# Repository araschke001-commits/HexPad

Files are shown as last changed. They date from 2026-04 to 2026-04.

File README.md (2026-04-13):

# HexPad
This is a macropad with 6 keys, a rotary encoder, and an oled display. Almost everything in the cad file for this project is customizable. You can add as many keys as you want, change the dimensions of the usb c port, the inside dimensions, the wall dimensions, and basically everything else.

You would use my project by pressing the keys to perform specific functions on the computer, like a simple key press like the number 1, or later I might change it to open a site or type a password in. The rotary encoder is to change volume and mute/unmute it. The oled display is to indicate if a button was pressed/changed.

The reason why I made this project is to learn how to build things like this project so in the future I can make other things similar to this.

## Features:
- 3d printed case
- 6 keys (2 rows of 3)
- 0.91" OLED display
- Rotary encoder
- Almost everything is customizable for the CAD design.

## CAD Model:
It is put together with 4 M3 Screws that go directly into the plastic of the case.

It is made of 2 separate 3d printed parts, the top and the bottom.

Here is the share link to the project: https://cad.onshape.com/documents/888c45d35c64a39055184245/w/6328c76e156d93114c845f2d/e/f25f9ae1fe243c3fda6125d5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

CAD Model:
Screenshot from 2026-04-12 15-23-01

Made in Onshape.

## PCB:
This PCB was made in KiCad.

Schematic:
Screenshot from 2026-04-07 09-58-41

PCB:
Screenshot from 2026-04-11 17-42-04

In hindsight, I maybe should have used a matrix to wire the switches, but it was simpler not to.

## Firmware:
This project uses C++ as firmware because I was unable to get the QMK firmware to work and I already had experience writing code in C++ (I did have to look up how to do some of the arduino stuff though).

The 6 keys act as a partial number pad for now. The oled is to display the last action, and the rotary encoder is to change volume and mute/unmute it.

## BOM:
This should be everything needed for my hackpad:
- Seeed Studio XIAO RP2040	(1x)
- Cherry MX Keycap - R2 (Opaque Black)	(6x)
- Cherry MX Brown 55g Tactile Switch	(6x)
- 0.91" OLED Display (1x)
- Rotary Encoder (1x)
- Rotary Encoder Knob (1x)
- M3 x 8mm Socket Button Head Screws	(4x)
- USB-C to USB-A Cable (3ft)	(1x)
- Custom PCB
- 3d Printed Case

## Build Guide
1. Order the components
2. Order the PCB
3. Solder the components onto the board
4. Move the firmware to the board using Arduino IDE
5. Put the pcb with everything attached in the case
6. Screw on the lid to the case

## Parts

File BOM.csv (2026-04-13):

Item | Description | Qty | Total Price (Without Tax or Shipping) | Source
Microcontroller | Seeed Studio XIAO RP2040 | 1 | $3.99 | https://www.seeedstudio.com/XIAO-RP2040-v1-0-p-5026.html
Keycaps | Cherry MX Keycap - R2 (Opaque Black) | 6 | $6.30 | https://www.sparkfun.com/cherry-mx-keycap-r2-opaque-black.html
Switches | Cherry MX Brown 55g Tactile Switch | 6 | $0.40 | https://mechanicalkeyboards.com/products/cherry-mx-brown-55g-tactile
OLED Display | 0.91" I2C OLED Display (SSD1306, 128×32, 4-pin) | 1 | $2.25 | https://www.aliexpress.us/item/3256804537576401.html
Rotary Encoder | EC11 rotary encoder (D-shaft, 5-pin, with push switch) | 1 | $2.03 | https://www.aliexpress.us/item/3256807756958688.html
Rotary Encoder Knob | 6mm D-shaft rubber encoder knob (11.5mm diameter) | 1 | $0.75 | https://www.adafruit.com/product/5093
Screws | M3 x 8mm Socket Button Head Screws | 4 | $0.80 | https://www.albanycountyfasteners.com/m3-050-x-8mm-button-head-socket-cap-screws-zinc-plated-steel-1111-150-0012/
Cable | USB-C to USB-A Cable (3ft) | 1 | $5.14 | https://www.walmart.com/ip/Auto-Drive-USB-C-to-USB-A-3ft-Charging-Data-Sync-Cable-PVC-Black-Single-Pack/245525955
PCB | Custom-designed PCB | 1 | $15.00 (Estimate) | N/A
3D Printed Case | 3D printed PLA case (Top and Bottom, Outsourced Printing) | 1 | $10.00 (Estimate) | N/A
Total | The total cost needed to make the HexPad | N/A | $46.66 | N/A

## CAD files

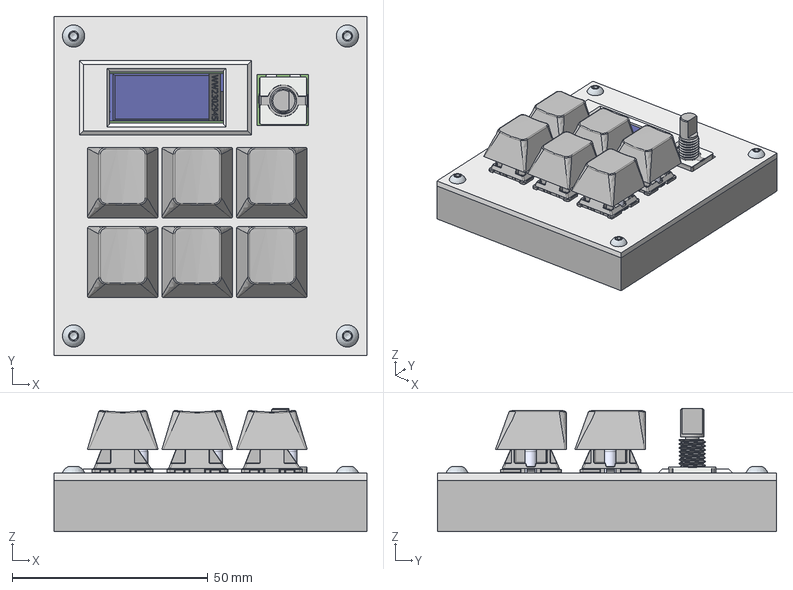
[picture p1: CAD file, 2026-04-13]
CAD Model/Full Part.step
80.0 x 86.7 x 31.5 mm
Cherry profile MX keycap x 6
Socket button head screw M3x0.5 x 8 x 4
MX? ??LEDLEDLED x 30
HexPad_PCB
type-c v2 x 24
Seeed Studio XIAO RP2040 v26 x 36
VDD
smd_button v3(Mirror)
MX ? ???_�___�1 x 6
MX? ?? ?? ?�2__??_�2____�_ x 6
MX ? ??��_�?�__ x 6
��ת������ x 6
main x 16
??___??__�_ x 12
smd_button v3
DOUT
DIN
VSS

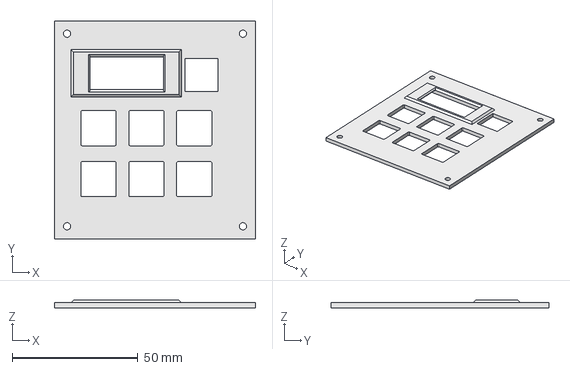
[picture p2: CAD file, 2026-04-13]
CAD Model/Top Part.step
80.0 x 86.7 x 3.00 mm

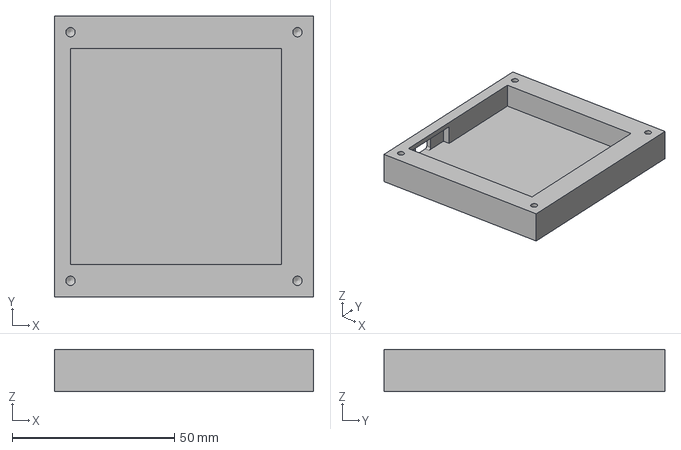
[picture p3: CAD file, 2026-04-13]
CAD Model/Bottom Part.step
80.0 x 86.7 x 13.0 mm

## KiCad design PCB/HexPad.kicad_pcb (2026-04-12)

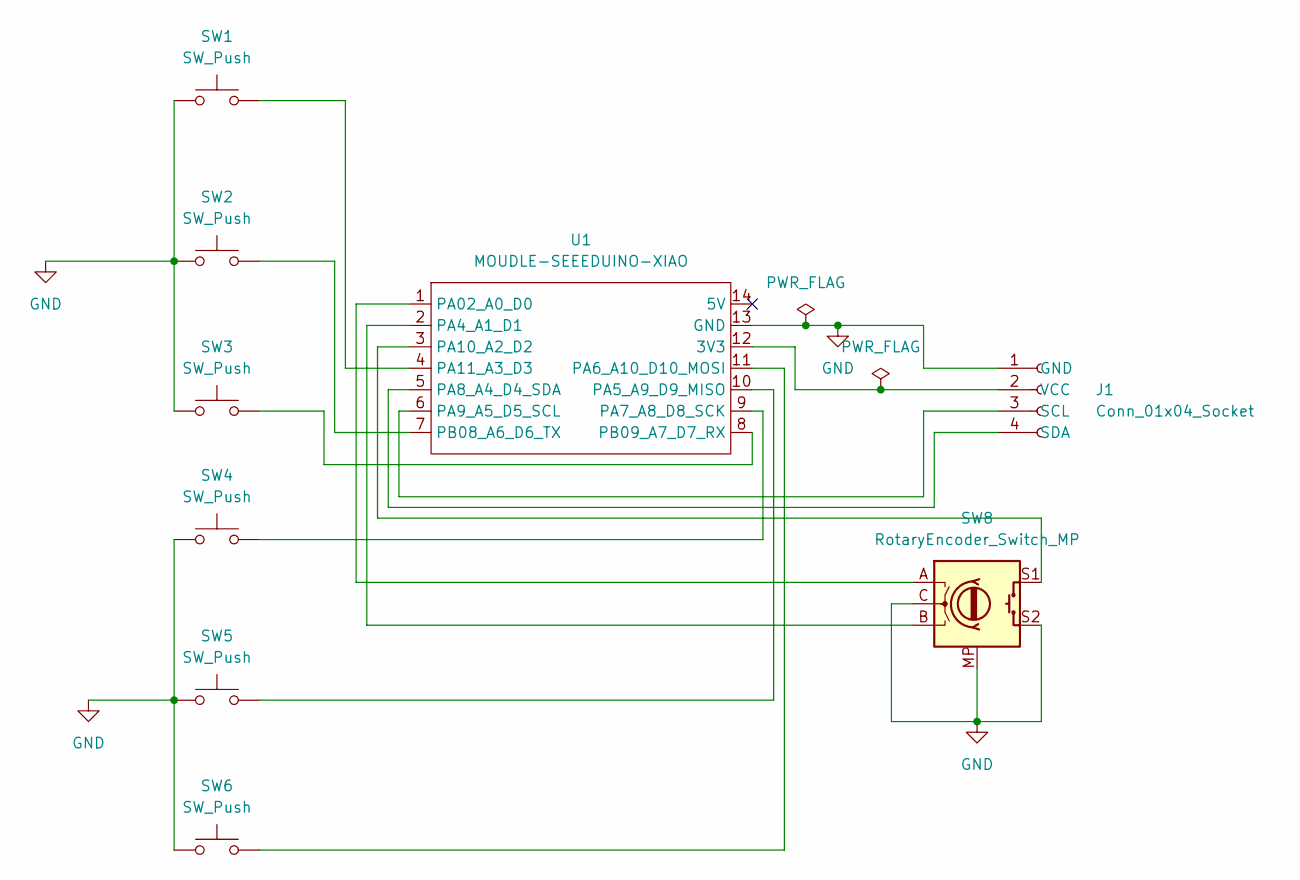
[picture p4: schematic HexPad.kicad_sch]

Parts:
J1: Conn_01x04_Socket; PinSocket_1x04_P2.54mm_Vertical
SW1, SW2, SW3, SW4, SW5, SW6: SW_Push; SW_Cherry_MX_1.00u_PCB
SW8: RotaryEncoder_Switch_MP; RotaryEncoder_Alps_EC11E-Switch_Vertical_H20mm
U1: MOUDLE-SEEEDUINO-XIAO; XIAO-Generic-Hybrid-14P-2.54-21X17.8MM

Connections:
GND: J1.1 (GND), SW1.1, SW2.1, SW3.1, SW4.1, SW5.1, SW6.1, SW8.C, SW8.MP, SW8.S2, U1.13 (GND)
unnamed: J1.3 (SCL), U1.6 (PA9_A5_D5_SCL)
unnamed: J1.4 (SDA), U1.5 (PA8_A4_D4_SDA)
unnamed: J1.2 (VCC), U1.12 (3V3)
unnamed: SW8.A, U1.1 (PA02_A0_D0)
unnamed: SW8.B, U1.2 (PA4_A1_D1)
unnamed: SW5.2, U1.10 (PA5_A9_D9_MISO)
unnamed: SW6.2, U1.11 (PA6_A10_D10_MOSI)
unnamed: SW4.2, U1.9 (PA7_A8_D8_SCK)
unnamed: SW8.S1, U1.3 (PA10_A2_D2)
unnamed: SW1.2, U1.4 (PA11_A3_D3)
unnamed: SW2.2, U1.7 (PB08_A6_D6_TX)
unnamed: SW3.2, U1.8 (PB09_A7_D7_RX)

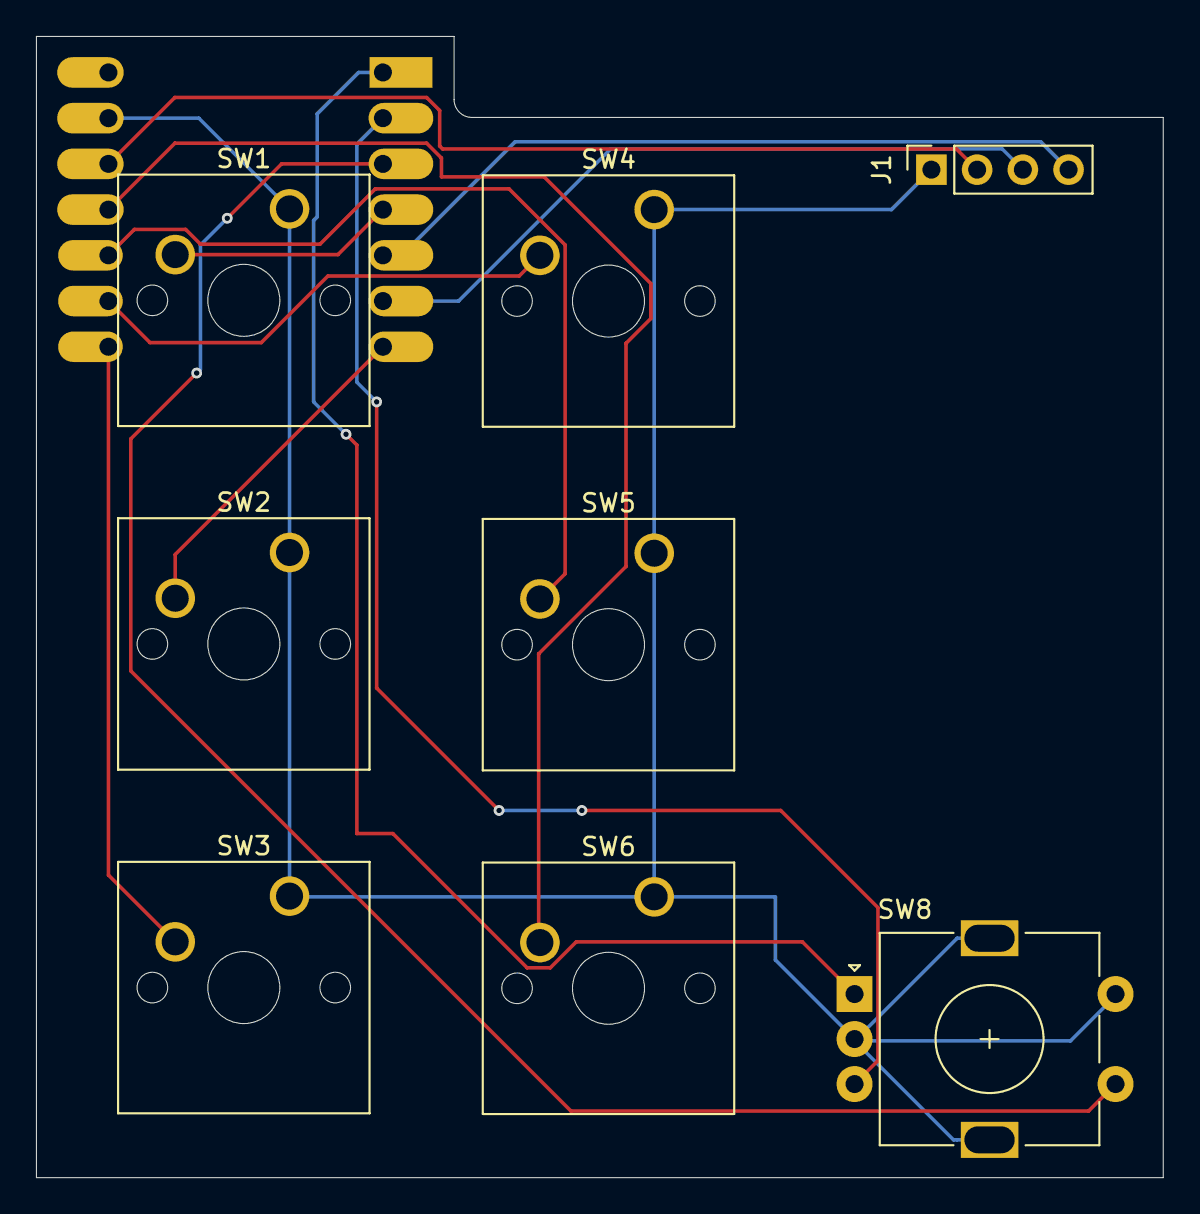
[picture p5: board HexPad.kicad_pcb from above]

Board: 2 copper layers, 62.6 x 63.4 mm, 9 parts (1 on the bottom side), 13 nets.

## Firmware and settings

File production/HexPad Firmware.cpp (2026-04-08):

#include <Keyboard.h>
#include <Encoder.h>
#include <Wire.h>
#include <Adafruit_GFX.h>
#include <Adafruit_SSD1306.h>

//OLED I2C pins
#define SDA_PIN 4
#define SCL_PIN 5

#define SCREEN_WIDTH 128
#define SCREEN_HEIGHT 32
Adafruit_SSD1306 display(SCREEN_WIDTH, SCREEN_HEIGHT, &Wire, -1);

//Keys
const int keyPins[6] = {3, 6, 7, 8, 9, 10};
bool lastKeyState[6];

//encoder
const int encA = 0;
const int encB = 1;
const int encBtn = 2;
Encoder knob(encA, encB);

long lastEncPos = 0;
bool lastBtnState = HIGH;

String lastAction = "Ready";

void updateDisplay() {
  display.clearDisplay();
  display.setTextSize(1);
  display.setTextColor(SSD1306_WHITE);
  display.setCursor(0, 10);
  display.print(lastAction);
  display.display();
}

void setup() {
  Keyboard.begin();

  //Setup for the keys
  for (int i = 0; i < 6; i++) {
    pinMode(keyPins[i], INPUT_PULLUP);
    lastKeyState[i] = HIGH;
  }

  //encoder button setup
  pinMode(encBtn, INPUT_PULLUP);

  //I2C setup
  Wire.setSDA(SDA_PIN);
  Wire.setSCL(SCL_PIN);
  Wire.begin(SDA_PIN, SCL_PIN);

  //OLED init, change to 0x3D if not working
  if (!display.begin(SSD1306_SWITCHCAPVCC, 0x3C)) {
    while (true); //stop if OLED fails
  }

  updateDisplay();
}

void loop() {
  //Reads if a key has been pressed
  for (int i = 0; i < 6; i++) {
  bool currentState = digitalRead(keyPins[i]);

  if (currentState == LOW && lastKeyState[i] == HIGH) {
    //Registers if a key was pressed on the computer and oled
    Keyboard.print("K" + String(i + 1));
    lastAction = "Key " + String(i + 1);
    updateDisplay();
  }

  lastKeyState[i] = currentState;
  }

  //Reads encoder rotation changes
  long newPos = knob.read() / 4;

  if (newPos != lastEncPos) {
    if (newPos > lastEncPos) {
      Keyboard.write(KEY_MEDIA_VOLUME_UP);
      lastAction = "Volume Up";
    } else {
      Keyboard.write(KEY_MEDIA_VOLUME_DOWN);
      lastAction = "Volume Down";
    }

    updateDisplay();
    lastEncPos = newPos;
  }

  //Handle encoder button (performs muting/unmuting voulme)
  bool btnState = digitalRead(encBtn);

  if (btnState == LOW && lastBtnState == HIGH) {
    Keyboard.write(KEY_MEDIA_MUTE);
    lastAction = "Mute/Unmute";
    updateDisplay();
    delay(50); //debounce
  }

  lastBtnState = btnState;
}

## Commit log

2026-03-29 Create Bill of Materials
2026-03-30 Rename Macropad v2.kicad_pcb to PCB/Macropad v2.kicad_pcb
    [Macropad v2.kicad_pcb]
2026-03-30 Rename Macropad v2.kicad_pro to PCB/Macropad v2.kicad_pro
2026-03-30 Rename Macropad v2.kicad_sch to PCB/Macropad v2.kicad_sch
    [Macropad v2.kicad_sch]
2026-03-30 Create Full Assembly
2026-03-31 Update and rename Hackpad BOM - Sheet1(1).csv to BOM.csv
    [BOM.csv, Hackpad BOM - Sheet1(1).csv]
2026-04-07 Include OLED in BOM.csv
    [BOM.csv]
2026-04-07 Fix BOM.csv
    [BOM.csv]
2026-04-08 Update BOM Total
    [BOM.csv]
2026-04-08 Removing Options from BOM.csv
    [BOM.csv]
2026-04-08 Clean BOM.csv
    [BOM.csv]
2026-04-11 Update Total
    [BOM.csv]
2026-04-13 Add Knob
    [BOM.csv]
2026-04-13 Remove Ambiguity
    [BOM.csv]
